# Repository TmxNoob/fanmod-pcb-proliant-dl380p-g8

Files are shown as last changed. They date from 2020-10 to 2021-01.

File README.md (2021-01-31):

### Made in KiCad

I provide only KiCad files because different PCB fabs require different export methods
Just google "[your preffered pcb fab] KiCad guide"

This mod is tested and needs some hacking around to work properly.
For example some of dl380p g8 fan revisions have thinner ears on the connectors so for those you need to have thinner pcbs (6mm ones from jlcpcb work).
To have the connector that goes into the motherboard make proper contact 80% of the time instead of 30% you need to solder it on at an angle (will add pics soon).
More info about the fanmod here:
https://github.com/TmxNoob/proliant-fan-mod

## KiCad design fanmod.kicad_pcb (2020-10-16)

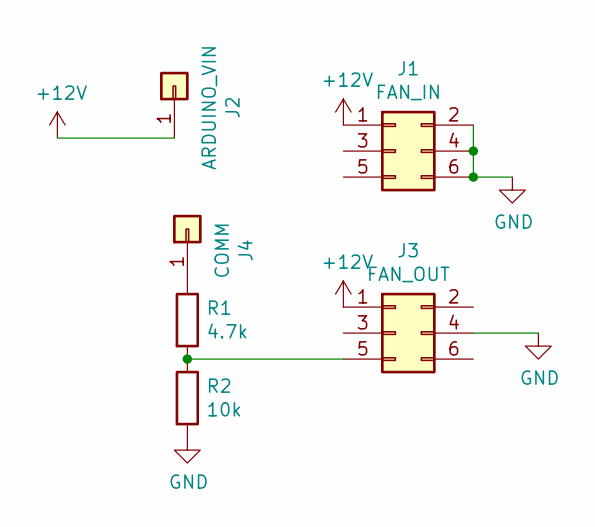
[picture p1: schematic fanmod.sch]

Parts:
J1: FAN_IN; PinSocket_2x03_P2.00mm_Vertical
J2: ARDUINO_VIN; PinHeader_1x01_P2.00mm_Vertical
J3: FAN_OUT; PinHeader_2x03_P2.00mm_Horizontal
J4: COMM; PinHeader_1x01_P2.00mm_Vertical
R1: 4.7k; R_0603_1608Metric_Pad1.05x0.95mm_HandSolder
R2: 10k; R_0603_1608Metric_Pad1.05x0.95mm_HandSolder

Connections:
+12V: J1.1, J2.1, J3.1
GND: J1.2, J1.4, J1.6, J3.4, R2.2
unnamed: J3.5, R1.2, R2.1
unnamed: J4.1, R1.1

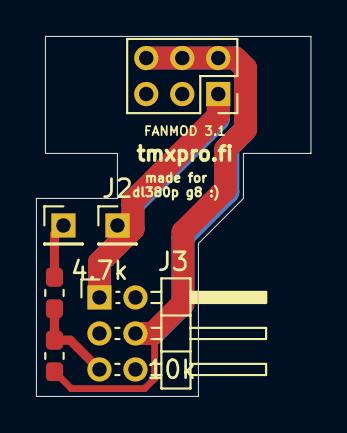
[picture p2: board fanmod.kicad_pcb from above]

Board: 2 copper layers, 15.2 x 20.0 mm, 6 parts (0 on the bottom side), 4 nets.
